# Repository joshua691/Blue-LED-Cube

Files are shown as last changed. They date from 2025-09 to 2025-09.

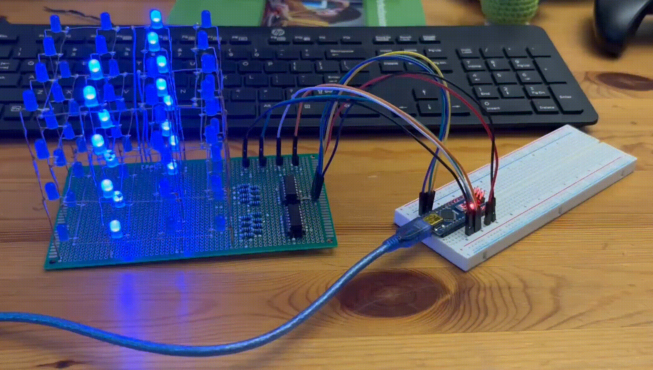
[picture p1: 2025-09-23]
images and gifs/Final Perf Board Construction.gif

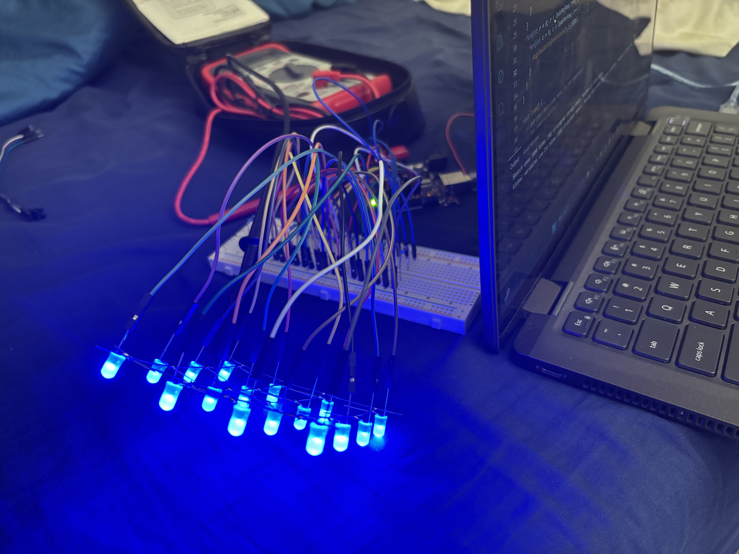
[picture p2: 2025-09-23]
images and gifs/Testing Individual Layer.jpg

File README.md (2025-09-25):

# 4×4×4 Blue LED Cube

A 4×4×4 LED cube controlled by an Arduino using transistors and multiplexing, achieving flicker-free animation at 250 Hz with a 25% refresh rate. This project demonstrates circuit design, embedded programming, and PCB layout skills using KiCad.

**Status: Completed**

## Overview
This project includes:
- Circuit schematic and PCB layout designed in KiCad
- Transistor-based control logic for efficient multiplexing
- Breadboard prototype and final soldered cube
- Modular design enabling microcontroller swaps and future feature expansion

## Features
- Flicker-free LED animation at **250 Hz**
- Power-efficient design using transistors and multiplexing
- Modular perfboard design for easy maintenance and upgrades
- Interactive features using ESP32 microcontroller

## Tools & Technologies
- **Hardware:** Arduino, 64x LEDs, 16x 470 ohm resistors, 4x transistors, 2x 74HC595 shift registers, perfboard
- **Software:** KiCad, Arduino IDE, C++
- **Other:** Breadboard prototyping, soldering

## Project Structure
- **Columns:** Each of the 16 LED columns shares a common anode, each connected to a pin on a 74HC595 shift register.
- **Layers:** Each of the 4 layers shares a common cathode, controlled by transistors to select which layer is grounded.
- **Control:** Arduino pins drive the shift registers and transistors to create multiplexed animation.

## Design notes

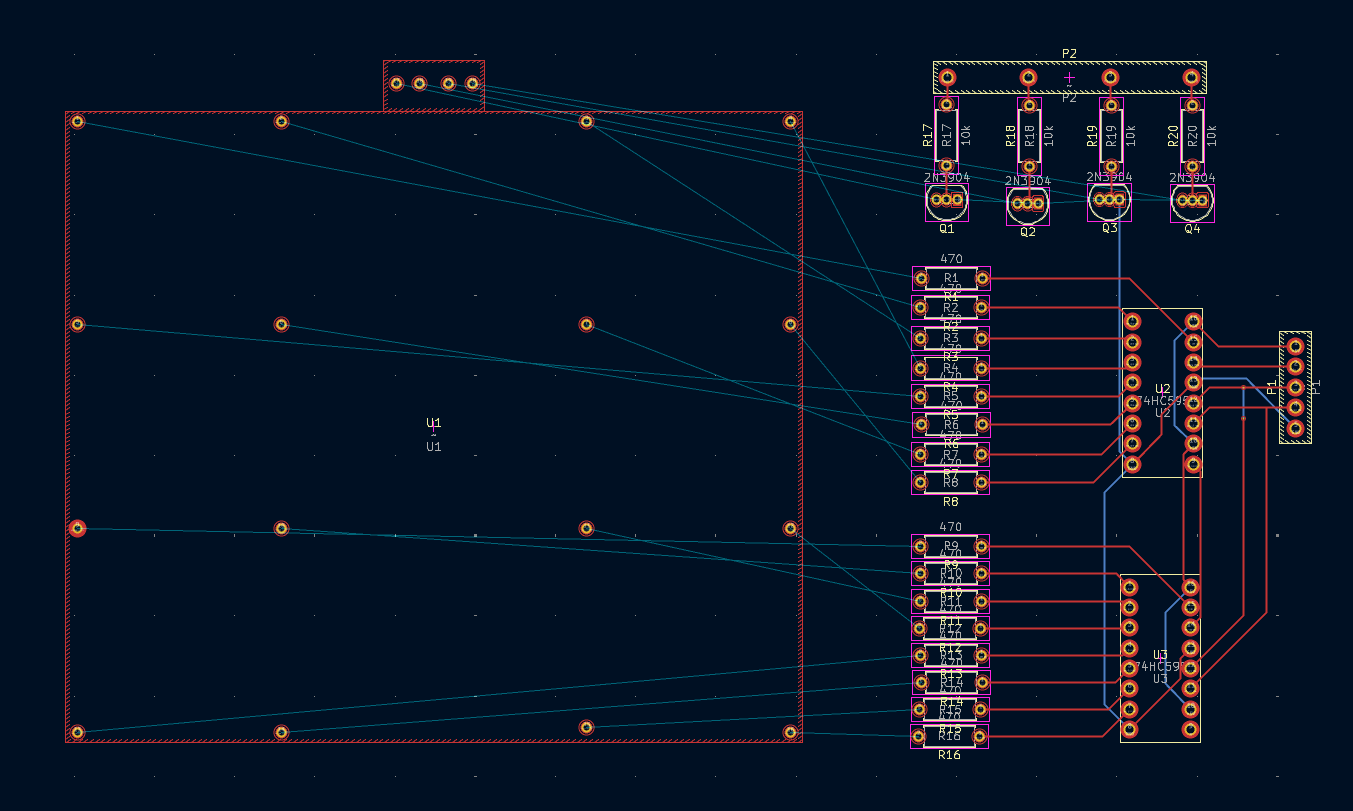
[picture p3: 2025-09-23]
schematics and perf board/Perf board layout.png

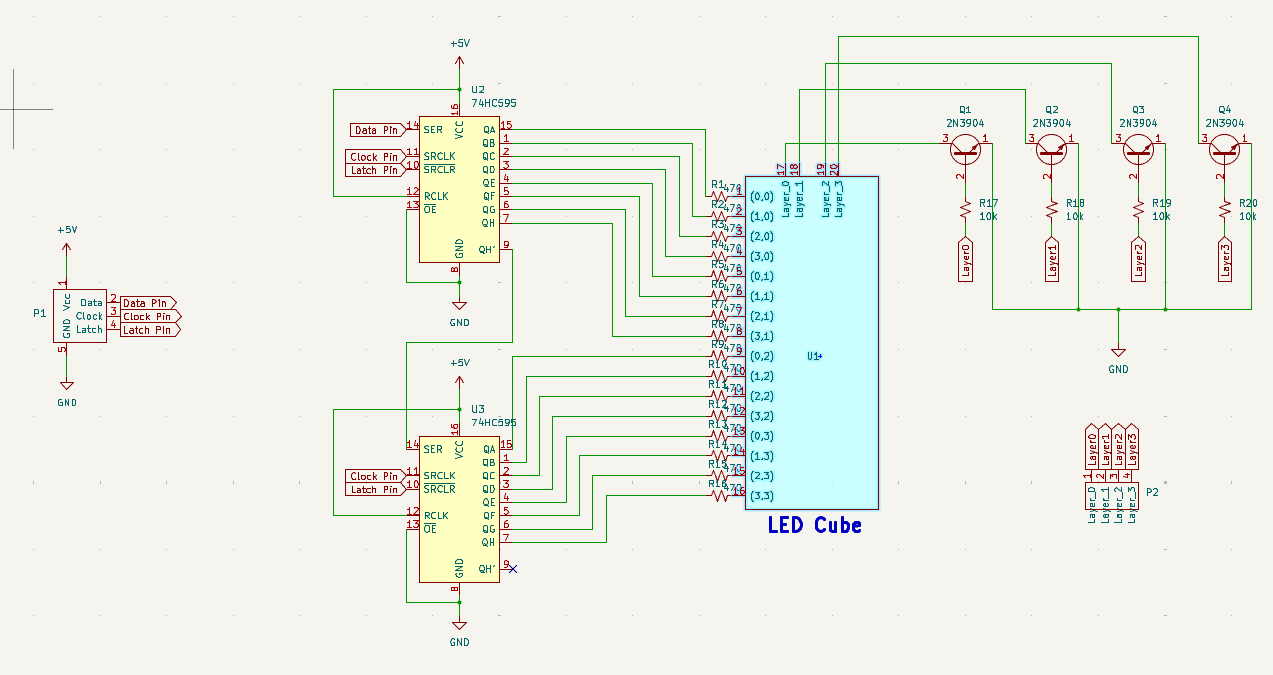
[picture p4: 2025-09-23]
schematics and perf board/Schematic.png

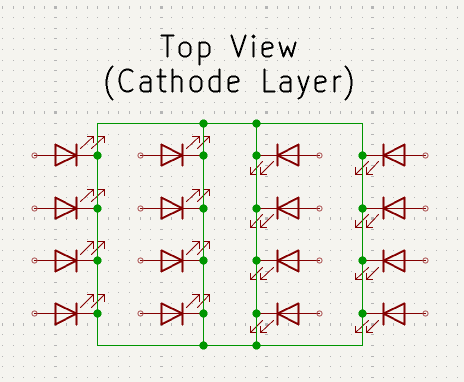
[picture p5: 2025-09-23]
schematics and perf board/Schematic (Cube Top View).png

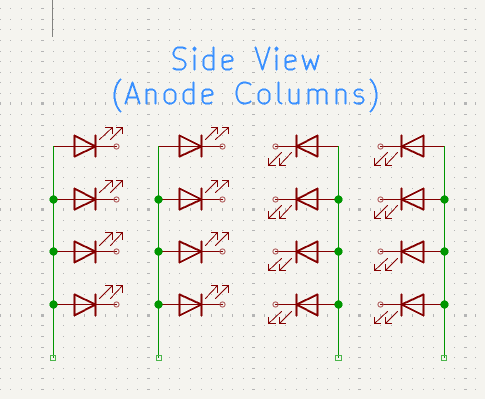
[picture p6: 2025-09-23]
schematics and perf board/Schematic (Cube Side View).png

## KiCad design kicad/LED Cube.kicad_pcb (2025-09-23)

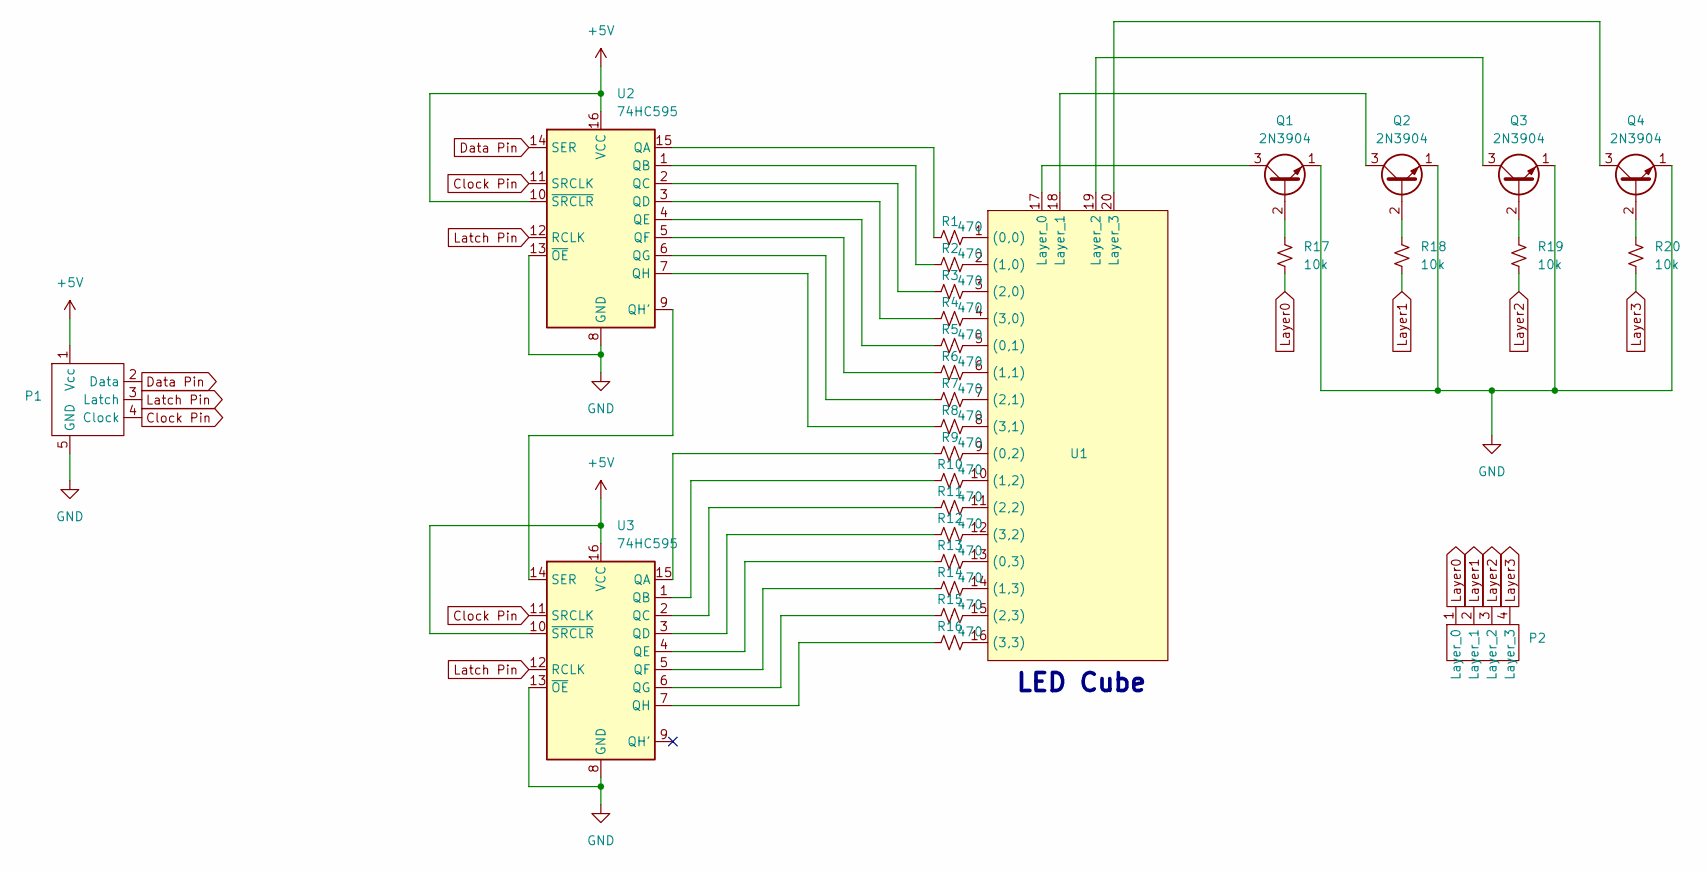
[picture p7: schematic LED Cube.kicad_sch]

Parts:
P1: Input_Pin_Connections
P2: Layer_Pin_Connections
Q1, Q2, Q3, Q4: 2N3904; TO-92_Inline
R1, R2, R3, R4, R5, R6, R7, R8, R9, R10, R11, R12, R13, R14, R15, R16: 470; R_Axial_DIN0207_L6.3mm_D2.5mm_P7.62mm_Horizontal
R17, R18, R19, R20: 10k; R_Axial_DIN0207_L6.3mm_D2.5mm_P7.62mm_Horizontal
U1: LED_Cube
U2, U3: 74HC595; 74HC595 Shift Register

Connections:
+5V: P1.1 (Vcc), U2.10 (~SRCLR), U2.16 (VCC), U3.10 (~SRCLR), U3.16 (VCC)
Clock Pin: P1.4 (Clock), U2.11 (SRCLK), U3.11 (SRCLK)
Data Pin: P1.2 (Data), U2.14 (SER)
GND: P1.5 (GND), Q1.1 (E), Q2.1 (E), Q3.1 (E), Q4.1 (E), U2.8 (GND), U2.13 (~OE), U3.8 (GND), U3.13 (~OE)
Latch Pin: P1.3 (Latch), U2.12 (RCLK), U3.12 (RCLK)
Layer0: P2.1 (Layer_0), R17.2
Layer1: P2.2 (Layer_1), R18.2
Layer2: P2.3 (Layer_2), R19.2
Layer3: P2.4 (Layer_3), R20.2
unnamed: Q1.2 (B), R17.1
unnamed: Q1.3 (C), U1.17 (Layer_0)
unnamed: Q2.2 (B), R18.1
unnamed: Q2.3 (C), U1.18 (Layer_1)
unnamed: Q3.2 (B), R19.1
unnamed: Q3.3 (C), U1.19 (Layer_2)
unnamed: Q4.2 (B), R20.1
unnamed: Q4.3 (C), U1.20 (Layer_3)
unnamed: R1.2, U1.1 ((0,0))
unnamed: R5.2, U1.5 ((0,1))
unnamed: R9.2, U1.9 ((0,2))
unnamed: R13.2, U1.13 ((0,3))
unnamed: R2.2, U1.2 ((1,0))
unnamed: R6.2, U1.6 ((1,1))
unnamed: R10.2, U1.10 ((1,2))
unnamed: R14.2, U1.14 ((1,3))
unnamed: R3.2, U1.3 ((2,0))
unnamed: R7.2, U1.7 ((2,1))
unnamed: R11.2, U1.11 ((2,2))
unnamed: R15.2, U1.15 ((2,3))
unnamed: R4.2, U1.4 ((3,0))
unnamed: R8.2, U1.8 ((3,1))
unnamed: R12.2, U1.12 ((3,2))
unnamed: R16.2, U1.16 ((3,3))
unnamed: R1.1, U2.15 (QA)
unnamed: R2.1, U2.1 (QB)
unnamed: R3.1, U2.2 (QC)
unnamed: R4.1, U2.3 (QD)
unnamed: R5.1, U2.4 (QE)
unnamed: R6.1, U2.5 (QF)
unnamed: R7.1, U2.6 (QG)
unnamed: U2.9 (QH'), U3.14 (SER)
unnamed: R8.1, U2.7 (QH)
unnamed: R9.1, U3.15 (QA)
unnamed: R10.1, U3.1 (QB)
unnamed: R11.1, U3.2 (QC)
unnamed: R12.1, U3.3 (QD)
unnamed: R13.1, U3.4 (QE)
unnamed: R14.1, U3.5 (QF)
unnamed: R15.1, U3.6 (QG)
unnamed: R16.1, U3.7 (QH)

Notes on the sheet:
LED Cube

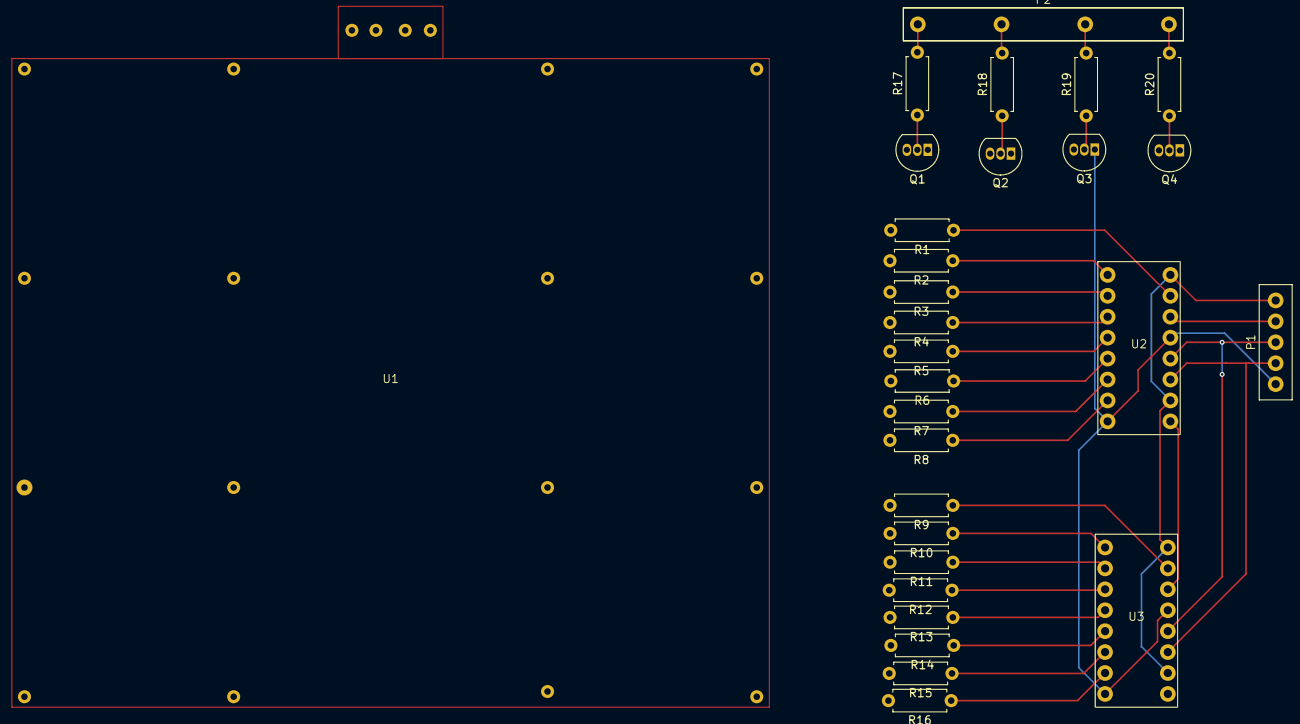
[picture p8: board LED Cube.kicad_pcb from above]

Board: 2 copper layers, 29 parts (0 on the bottom side), 50 nets.

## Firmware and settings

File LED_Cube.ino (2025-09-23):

// Delay time for multiplexing per layer is 1 millisecond

const int numLayers = 4;
const int numCols = 16;
const int layers[] = {A2,A3,A4,A5};
// const int ledPins[] = {0,1,2,3,4,5,6,7,8,9,10,11,12,13,A0,A1};

const int potPin = A6;
const int dataPin = 8;
const int clockPin = 9;
const int latchPin = 10;

const int trigPin = 6;
const int echoPin = 7;

void turnOffEverything(uint16_t order);
void shiftOutLights();
void display(uint16_t layout0, uint16_t layout1, uint16_t layout2, uint16_t layout3);
void loopThroughAll();
int rainPos[] = {0,0,0,0};
void rain();
void terrible();
void spinningPlane();
void waves();
void distanceSensor();
void slidingSquare();

void setup() {
  pinMode(potPin,INPUT);
  for(int i = 0; i < numLayers; i++) {
    pinMode(layers[i],OUTPUT);
  }
  pinMode(dataPin,OUTPUT);
  pinMode(clockPin,OUTPUT);
  pinMode(latchPin,OUTPUT);

  pinMode(trigPin,OUTPUT);
  pinMode(echoPin,INPUT);
  // for(int i = 0; i < numCols; i++) {
  //   pinMode(ledPins[i],OUTPUT);
  // }
  turnOffEverything();
}

void loop() {
  rain();
}

void turnOffEverything() {
  for(int i = 0; i < numLayers; i++) {
    digitalWrite(layers[i],LOW);
  }
  shiftOutLights(0x0000);
}

// A 16-bit integer is given to shift out to the shift registers driving the LED columns
// 1 turns the column one and 0 turns it off
void shiftOutLights(uint16_t order) {
  byte first = order & 0xFF;
  byte second = (order >> 8) & 0xFF;
  digitalWrite(latchPin,LOW);
  shiftOut(dataPin,clockPin,LSBFIRST,first);
  shiftOut(dataPin,clockPin,LSBFIRST,second);
  digitalWrite(latchPin,HIGH);
}

// An image is given to be displayed by shifting out 16 bits for each layer
// The duration is how long to display the given image
void display(uint16_t layout0, uint16_t layout1, uint16_t layout2, uint16_t layout3, int duration) {
  uint16_t layouts[numLayers] = {layout0,layout1,layout2,layout3};
  for(int t = 0; t < duration/4; t++) {
    for(int i = 0; i < numLayers; i++) {
      shiftOutLights(layouts[i]);
      digitalWrite(layers[i],HIGH);
      delay(1);
      digitalWrite(layers[i],LOW);
    }
  }
}

void loopThroughAll() {
  display(0b1111111111111111,0b1111111111111111,0b1111111111111111,0b1111111111111111,1);
}

void terrible() {
  // int timePerLetter = 500;
  // for(int i = 0; i < timePerLetter/4; i++) {
  //   for(int l = 0; l < ledsPerRow; l++) {
  //     if(l == 3) {
  //       lightLeds(0);
  //     } else if (l == 2) {
  //       lightLeds(0b0000000000000111);
  //     } else {
  //       lightLeds(0b0000000000000010);
  //     }
  //     digitalWrite(layers[l],HIGH);
  //     delay(1);
  //     digitalWrite(layers[l],LOW);
  //   }
  // }
  // for(int i = 0; i < timePerLetter/4; i++) {
  //   for(int l = 0; l < ledsPerRow; l++) {
  //     if(l == 2) {
  //       lightLeds(0b0000000000000111);
  //     } else if (l == 1) {
  //       lightLeds(0b0000000000000001);
  //     } else {
  //       lightLeds(0b0000000000001111);
  //     }
  //     digitalWrite(layers[l],HIGH);
  //     delay(1);
  //     digitalWrite(layers[l],LOW);
  //   }
  // }
}

void spinningPlane() {
  int timePerImage = 80;
  int timePerRotation = 2000;

  for(int o = 0; o < timePerRotation; o+=(timePerImage*6)) {
    for(int i = 0; i < timePerImage/4; i++) {
      for(int l = 0; l < numLayers; l++) {
        shiftOutLights(0b0001001001001000);
        digitalWrite(layers[l],HIGH);
        delay(1);
        digitalWrite(layers[l],LOW);
      }
    }
    for(int i = 0; i < timePerImage/4; i++) {
      for(int l = 0; l < numLayers; l++) {
        shiftOutLights(0b0010001001000100);
        digitalWrite(layers[l],HIGH);
        delay(1);
        digitalWrite(layers[l],LOW);
      }
    }
    for(int i = 0; i < timePerImage/4; i++) {
      for(int l = 0; l < numLayers; l++) {
        shiftOutLights(0b0100010000100010);
        digitalWrite(layers[l],HIGH);
        delay(1);
        digitalWrite(layers[l],LOW);
      }
    }
    for(int i = 0; i < timePerImage/4; i++) {
      for(int l = 0; l < numLayers; l++) {
        shiftOutLights(0b1000010000100001);
        digitalWrite(layers[l],HIGH);
        delay(1);
        digitalWrite(layers[l],LOW);
      }
    }
    for(int i = 0; i < timePerImage/4; i++) {
      for(int l = 0; l < numLayers; l++) {
        shiftOutLights(0b0000110000110000);
        digitalWrite(layers[l],HIGH);
        delay(1);
        digitalWrite(layers[l],LOW);
      }
    }
    for(int i = 0; i < timePerImage/4; i++) {
      for(int l = 0; l < numLayers; l++) {
        shiftOutLights(0b0000001111000000);
        digitalWrite(layers[l],HIGH);
        delay(1);
        digitalWrite(layers[l],LOW);
      }
    }
  }

  // Change axis of rotation
  for(int o = 0; o < timePerRotation; o+=(timePerImage*6)) {
    display(0b1111000000000000,0b0000111100000000,0b0000000011110000,0b0000000000001111,timePerImage);
    display(0b0000000000000000,0b1111111100000000,0b0000000011111111,0b0000000000000000,timePerImage);
    display(0b0000000000000000,0b0000000011111111,0b1111111100000000,0b0000000000000000,timePerImage);
    display(0b0000000000001111,0b0000000011110000,0b0000111100000000,0b1111000000000000,timePerImage);
    display(0b0000000011110000,0b0000000011110000,0b0000111100000000,0b0000111100000000,timePerImage);
    display(0b0000111100000000,0b0000111100000000,0b0000000011110000,0b0000000011110000,timePerImage);
  }
}

void waves() {
  int timePerImage = 60;
  display(0b1111011100110001,0b0110001100010000,0b0110001100010000,0b0011000100000000,timePerImage);
  display(0b0111001100011000,0b0011000100000000,0b0011000100000000,0b0001000000001000,timePerImage);
  display(0b0011000110001100,0b0001000000001000,0b0001000000001000,0b0000000010001100,timePerImage);
  display(0b0001100011001110,0b0000000010001100,0b0000000010001100,0b0000100011000110,timePerImage);
  display(0b1000110011101111,0b0000100011000110,0b0000100011000110,0b1000110001100011,timePerImage);
  display(0b1100111011110111,0b1000110001100011,0b1000110001100011,0b1100011000110001,timePerImage);
  display(0b1110111101110011,0b1100011000110001,0b1100011000110001,0b0110001100010000,timePerImage);
}

void slidingSquare() {
  const int stopTime = 500;
  const int moveTime = 500;
  display(0x8888,0x8888,0x8888,0x8888,stopTime);

  display(0x4444,0x8888,0x8888,0x8888,moveTime/5);
  display(0x2222,0x4444,0x8888,0x8888,moveTime/5);
  display(0x1111,0x2222,0x4444,0x8888,moveTime/5);
  display(0x1111,0x1111,0x2222,0x4444,moveTime/5);
  display(0x1111,0x1111,0x1111,0x2222,moveTime/5);
  

  display(0x1111,0x1111,0x1111,0x1111,stopTime);
  
  display(0x2222,0x1111,0x1111,0x1111,moveTime/5);
  display(0x4444,0x2222,0x1111,0x1111,moveTime/5);
  display(0x8888,0x4444,0x2222,0x1111,moveTime/5);
  display(0x8888,0x8888,0x4444,0x2222,moveTime/5);
  display(0x8888,0x8888,0x8888,0x4444,moveTime/5);
}

void rain() {
  for(int i = numLayers-1; i > 0; i--) {
    rainPos[i] = rainPos[i-1];
  }
  rainPos[0] = random(16);
  display(1<<rainPos[0],1<<rainPos[1],1<<rainPos[2],1<<rainPos[3],160);
}

void distanceSensor() {
  const unsigned long timeout = 29000;
  digitalWrite(trigPin,HIGH);
  delayMicroseconds(10);
  digitalWrite(trigPin,LOW);
  long distance = pulseIn(echoPin,HIGH,timeout);
}

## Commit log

2025-09-23 Initial commit: KiCad files
    [LED Cube.kicad_pcb, LED Cube.kicad_sch]
2025-09-23 added kicad files to one folder
    [LED Cube.kicad_pcb, LED Cube.kicad_sch]
2025-09-23 adding schematic and PCB layout
2025-09-23 added schematics for top and side view
    [LED Cube.kicad_sch]
2025-09-23 Add files via upload
    added Arduino code
